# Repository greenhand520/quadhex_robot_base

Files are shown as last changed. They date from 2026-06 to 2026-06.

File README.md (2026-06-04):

## 简介

### 项目概述

### 电源架构

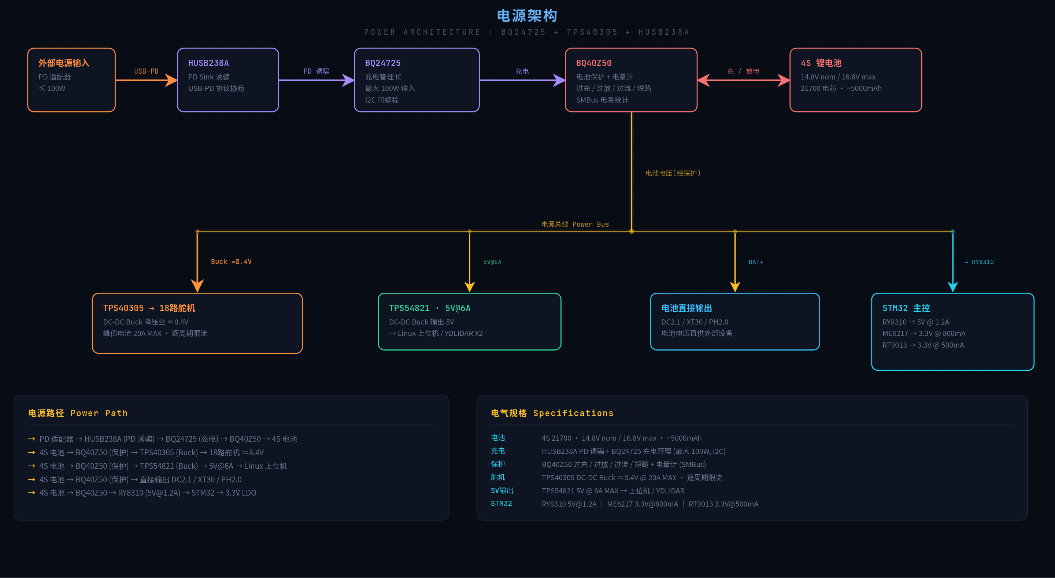
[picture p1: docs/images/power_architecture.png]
电源架构


> 网页版本请访问 → [Power Architecture (HTML)](https://greenhand520.github.io/quadhex_robot_base/docs/power_architecture.html)

## 硬件与结构

### PCB 设计

所有PCB（均使用 [JLCEDA Pro](https://pro.lceda.cn/editor/) 进行设计，对应工程文件位于 [`hardware`](hardware/) 目录下。

> 最新可以直接在线查看的 PCB 项目文件可以访问 [oshwhub 发布页面](https://oshwhub.com/) （等待所有PCB测试通过）。

### 3D 打印与机械结构

项目提供一个 3D 打印的 4S 21700 电池仓，可安装 BQ40Z50 保护板，建模参数适应 **PETG 材料** 和 **Bambu Lab A1** 打印机。其他材料和打印机未经测试，结构强度和尺寸无法保证。打印文件和物料清单（BOM）位于 [`mechanism`](mechanism/) 目录下：

```
mechanism/
├── stl/                    # 最新可打印 STL 文件
├── BOM.md                  # 物料清单（紧固件等）(TODO)
└── assembly_guide.md       # 装配指南(TODO)
```

4S 21700 电池仓 结构如下:

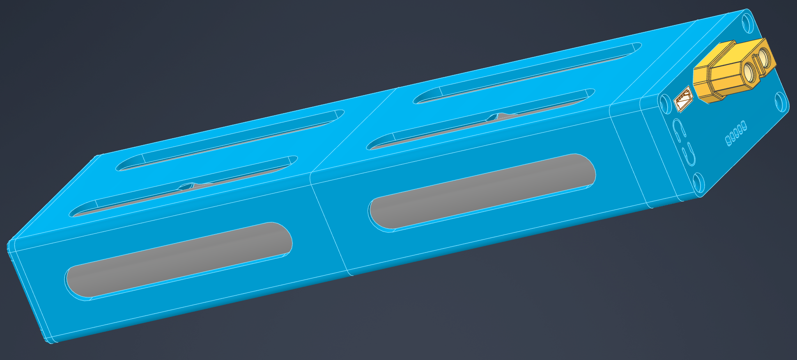
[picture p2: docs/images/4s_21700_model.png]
4S 21700 电池仓


## 参与贡献

欢迎参与贡献！请阅读以下指南：

TODO

---

## 开源许可

本项目基于 **GNU 通用公共许可证 v3.0** 开源——详见 [LICENSE](LICENSE) 文件。

硬件设计（PCB 原理图、3D 模型）基于 **CERN 开放硬件许可 v2（CERN-OHL-P-2.0）** 开源。

---

## 致谢

排名不分先后

- [ROS2](https://docs.ros.org/) — 机器人操作系统 2
- [Xiaomi MiMo Token Plan](https://platform.xiaomimimo.com/token-plan) — 小米 MiMo 大模型 Token 订阅计划
- [CLion](https://www.jetbrains.com/clion/) — 为顺畅工作流程和高效开发而设计的跨平台 C/C++ 集成开发环境
- [MicroROS](https://micro.ros.org/) — 面向微控制器的 ROS2
- [JLCEDA](https://lceda.cn/) — PCB 设计工具（立创 EDA）
- [Bambu Lab](https://bambulab.com/) — 3D 打印平台

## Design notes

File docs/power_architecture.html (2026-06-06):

# 电源架构

Power Architecture · BQ24725 + TPS40305 + HUSB238A

外部电源输入

PD 适配器
≤ 100W

HUSB238A

PD Sink 诱骗
USB-PD 协议协商

BQ24725

充电管理 IC
最大 100W 输入
I2C 可编程

BQ40Z50

电池保护 + 电量计
过充 / 过放 / 过流 / 短路
SMBus 电量统计

4S 锂电池

14.8V nom / 16.8V max
21700 电芯 · ~5000mAh

TPS40305 → 18路舵机

DC-DC Buck 降压至 ≈8.4V
峰值电流 20A MAX · 逐周期限流

TPS54821 · 5V@6A

DC-DC Buck 输出 5V
→ Linux 上位机 / YDLIDAR X2

电池直接输出

DC2.1 / XT30 / PH2.0
电池电压直供外部设备

STM32 主控

RY8310 → 5V @ 1.2A
ME6217 → 3.3V @ 800mA
RT9013 → 3.3V @ 500mA

### 电源路径 Power Path

- PD 适配器 → HUSB238A (PD 诱骗) → BQ24725 (充电) → BQ40Z50 → 4S 电池
- 4S 电池 → BQ40Z50 (保护) → TPS40305 (Buck) → 18路舵机 ≈8.4V
- 4S 电池 → BQ40Z50 (保护) → TPS54821 (Buck) → 5V@6A → Linux 上位机
- 4S 电池 → BQ40Z50 (保护) → 直接输出 DC2.1 / XT30 / PH2.0
- 4S 电池 → BQ40Z50 → RY8310 (5V@1.2A) → STM32 → 3.3V LDO

### 电气规格 Specifications

电池4S 21700 · 14.8V nom / 16.8V max · ~5000mAh 充电HUSB238A PD 诱骗 + BQ24725 充电管理 (最大 100W, I2C) 保护BQ40Z50 过充 / 过放 / 过流 / 短路 + 电量计 (SMBus) 舵机TPS40305 DC-DC Buck ≈8.4V @ 20A MAX · 逐周期限流 5V输出TPS54821 5V @ 6A MAX → 上位机 / YDLIDAR STM32RY8310 5V@1.2A │ ME6217 3.3V@800mA │ RT9013 3.3V@500mA

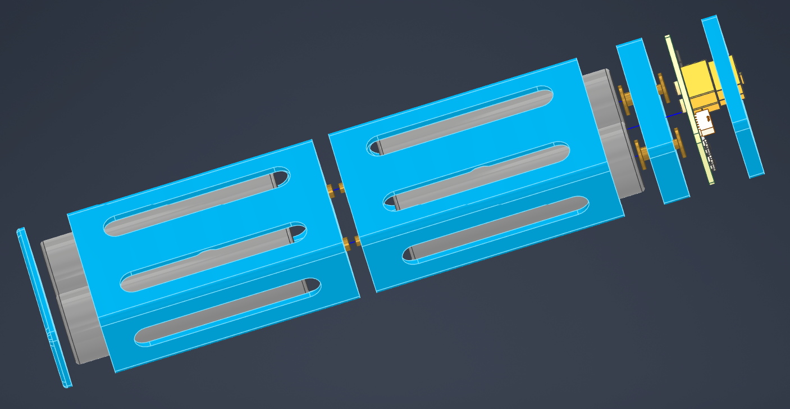
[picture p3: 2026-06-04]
docs/images/4s_21700_ipn.png

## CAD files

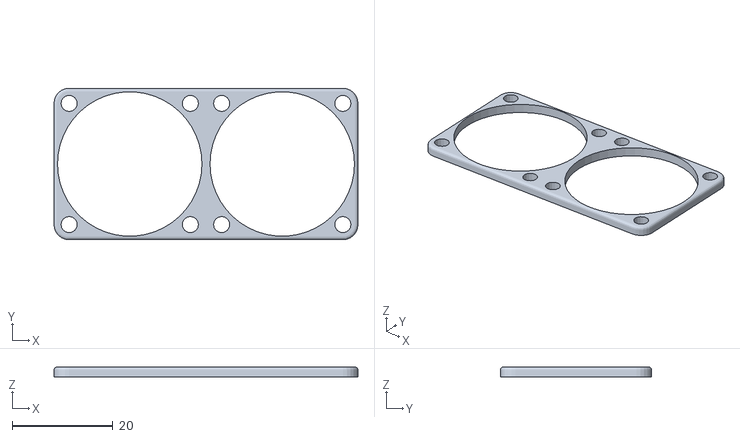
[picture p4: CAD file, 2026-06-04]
mechanism/stl/3010_fan_bracket_full.stl
60.2 x 30.0 x 2.00

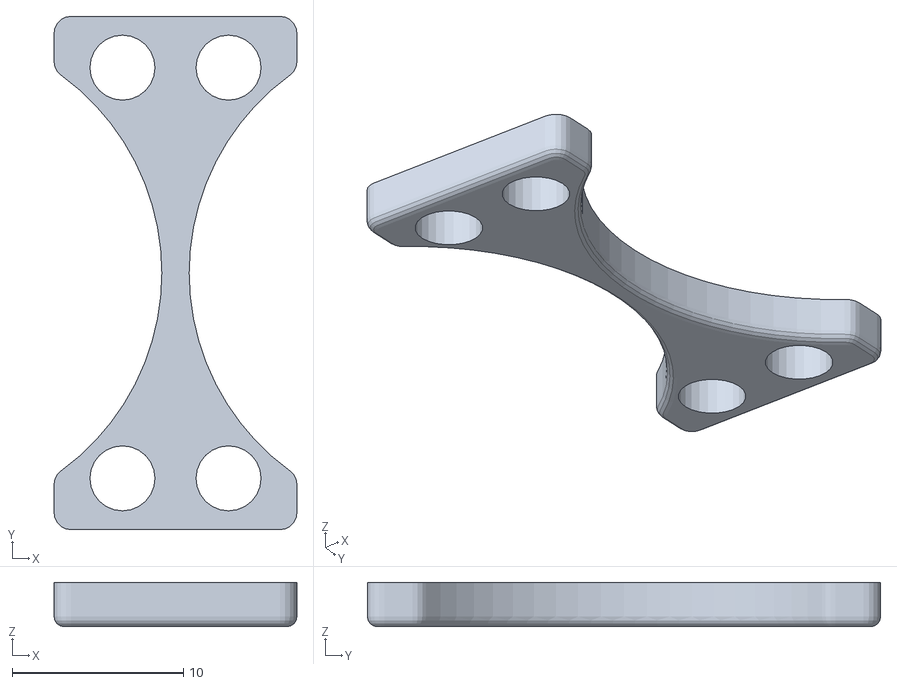
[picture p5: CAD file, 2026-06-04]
mechanism/stl/3010_fan_bracket.stl
14.2 x 30.0 x 2.60

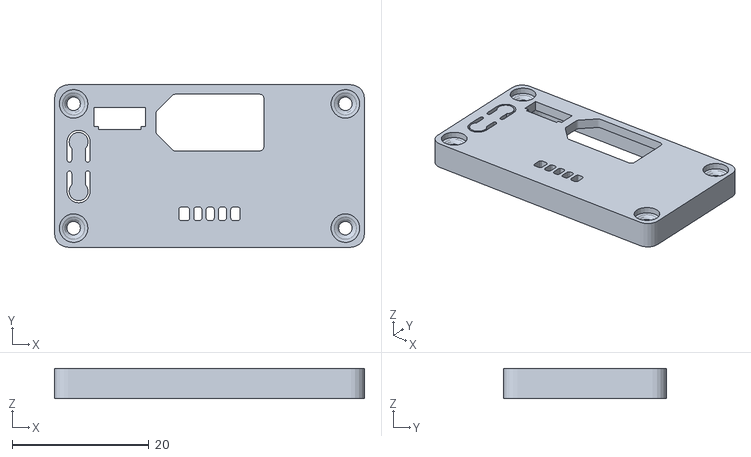
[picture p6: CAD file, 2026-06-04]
mechanism/stl/BZ40Z50_cover.stl
45.4 x 23.8 x 4.40

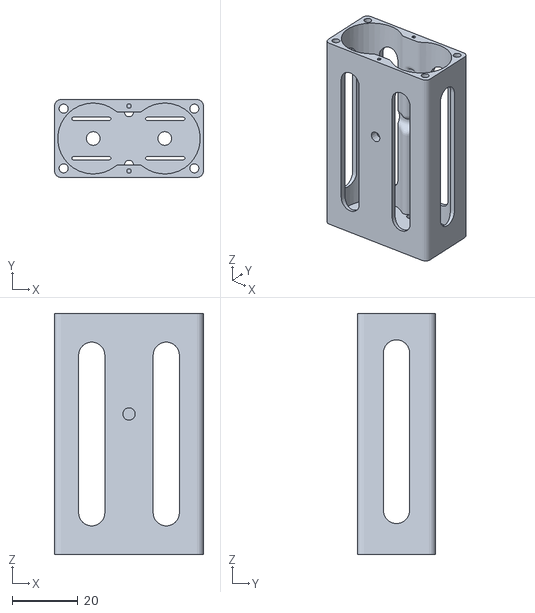
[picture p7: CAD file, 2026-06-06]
mechanism/stl/21700_battery_holder_bottom.stl
45.4 x 23.8 x 73.4

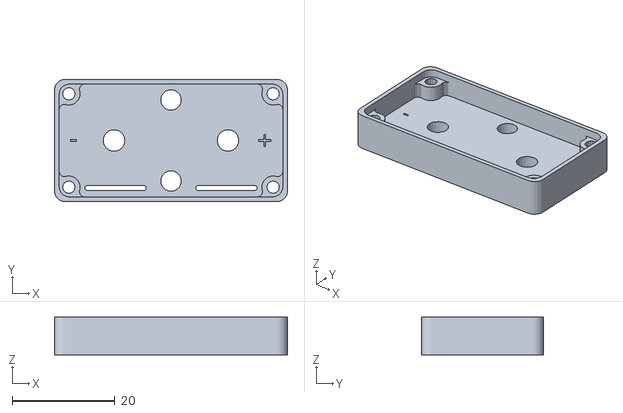
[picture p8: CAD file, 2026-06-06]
mechanism/stl/21700_battery_holder_cover.stl
45.4 x 23.8 x 7.40

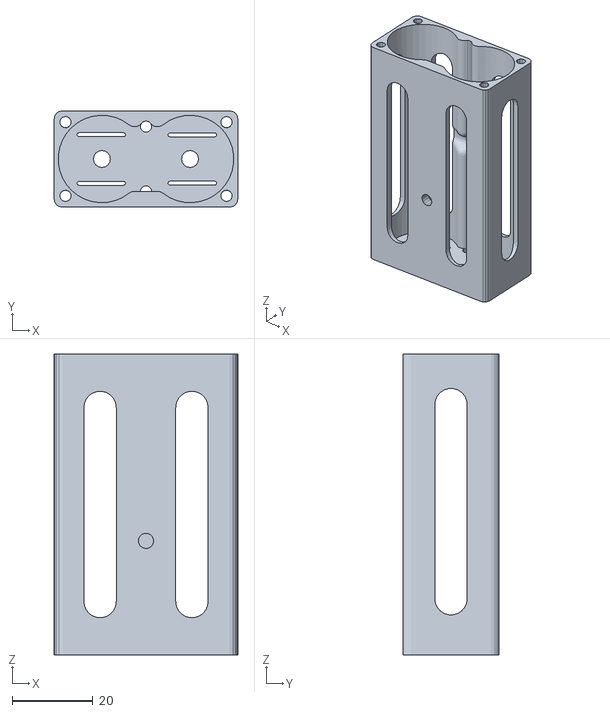
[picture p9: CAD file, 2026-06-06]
mechanism/stl/21700_battery_holder_top.stl
45.4 x 23.8 x 74.4

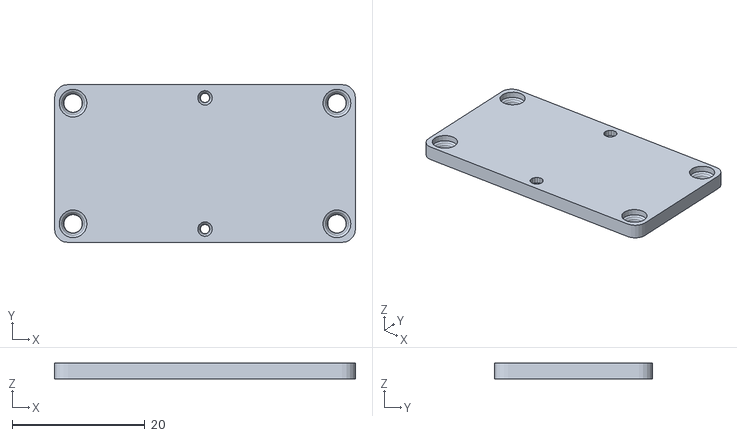
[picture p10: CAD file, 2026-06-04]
mechanism/stl/21700_battery_holder_bottom_cover.stl
45.4 x 23.8 x 2.40

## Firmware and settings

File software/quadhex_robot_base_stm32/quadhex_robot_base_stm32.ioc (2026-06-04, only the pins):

Mcu.UserName=STM32F405RGTx
PA10.GPIO_Label=BUZZ
PA10.Signal=S_TIM1_CH3
PA11.Signal=USB_OTG_FS_DM
PA12.Signal=USB_OTG_FS_DP
PA13.Signal=SYS_JTMS-SWDIO
PA14.Signal=SYS_JTCK-SWCLK
PA2.Signal=USART2_TX
PA3.Signal=USART2_RX
PA4.GPIO_Label=CS1_MPU
PA4.Signal=GPIO_Output
PA5.Signal=SPI1_SCK
PA6.Signal=SPI1_MISO
PA7.Signal=SPI1_MOSI
PA9.Signal=USB_OTG_FS_VBUS
PB10.Signal=I2C2_SCL
PB11.Signal=I2C2_SDA
PB2.GPIO_Label=HUSB238A_INT
PB2.Signal=GPXTI2
PB7.GPIO_Label=WS2812
PB7.Signal=S_TIM4_CH2
PB8.Signal=I2C1_SCL
PB9.Signal=I2C1_SDA
PC0.GPIO_Label=BC_IOUT
PC0.Signal=ADCx_IN10
PC1.GPIO_Label=TEMP1_ADC
PC1.Signal=ADCx_IN11
PC12.Signal=UART5_TX
PC13-ANTI_TAMP.GPIO_Label=VM_EN
PC13-ANTI_TAMP.Signal=GPIO_Output
PC14-OSC32_IN.GPIO_Label=AC_OK
PC14-OSC32_IN.Signal=GPXTI14
PC15-OSC32_OUT.GPIO_Label=MPU_INT
PC15-OSC32_OUT.Signal=GPXTI15
PC2.GPIO_Label=TEMP2_ADC
PC2.Signal=ADCx_IN12
PC3.GPIO_Label=SVM_ADC
PC3.Signal=ADCx_IN13
PC4.GPIO_Label=FAN_EN
PC4.Signal=GPIO_Output
PC5.GPIO_Label=CV_ADC
PC5.Signal=ADCx_IN15
PD2.Signal=UART5_RX
PH0-OSC_IN.Signal=RCC_OSC_IN
PH1-OSC_OUT.Signal=RCC_OSC_OUT

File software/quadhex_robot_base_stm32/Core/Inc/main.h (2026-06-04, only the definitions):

#define VM_EN_Pin GPIO_PIN_13
#define VM_EN_GPIO_Port GPIOC
#define AC_OK_Pin GPIO_PIN_14
#define AC_OK_GPIO_Port GPIOC
#define AC_OK_EXTI_IRQn EXTI15_10_IRQn
#define MPU_INT_Pin GPIO_PIN_15
#define MPU_INT_GPIO_Port GPIOC
#define MPU_INT_EXTI_IRQn EXTI15_10_IRQn
#define BC_IOUT_Pin GPIO_PIN_0
#define BC_IOUT_GPIO_Port GPIOC
#define TEMP1_ADC_Pin GPIO_PIN_1
#define TEMP1_ADC_GPIO_Port GPIOC
#define TEMP2_ADC_Pin GPIO_PIN_2
#define TEMP2_ADC_GPIO_Port GPIOC
#define SVM_ADC_Pin GPIO_PIN_3
#define SVM_ADC_GPIO_Port GPIOC
#define CS1_MPU_Pin GPIO_PIN_4
#define CS1_MPU_GPIO_Port GPIOA
#define FAN_EN_Pin GPIO_PIN_4
#define FAN_EN_GPIO_Port GPIOC
#define CV_ADC_Pin GPIO_PIN_5
#define CV_ADC_GPIO_Port GPIOC
#define HUSB238A_INT_Pin GPIO_PIN_2
#define HUSB238A_INT_GPIO_Port GPIOB
#define BUZZ_Pin GPIO_PIN_10
#define BUZZ_GPIO_Port GPIOA
#define WS2812_Pin GPIO_PIN_7
#define WS2812_GPIO_Port GPIOB

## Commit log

2026-06-06 update model & power arch desc
    [21700_battery_holder_bottom.stl, 21700_battery_holder_cover.stl, 21700_battery_holder_top.stl]
2026-06-06 update power arch desc

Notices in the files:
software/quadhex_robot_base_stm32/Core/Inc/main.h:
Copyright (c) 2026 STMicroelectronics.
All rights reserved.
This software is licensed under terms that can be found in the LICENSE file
